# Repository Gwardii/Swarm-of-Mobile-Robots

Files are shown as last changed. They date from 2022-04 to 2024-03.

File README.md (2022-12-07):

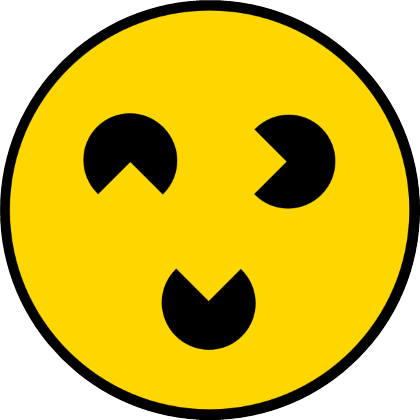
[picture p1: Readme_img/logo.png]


# TGS - The Great Swarm 

Academic project of the swarm of mobile robots - system for controlling and monitoring mobile robots with differential drive. The system consists of a graphical user interface, mobile robot software and software for detecting obstacles. 

## Graphical User Interface
A graphical user interface was created with the use of the Tkinter package. The application allows users to control the mobile robots with the help of control buttons and by assigning the coordinates of the target. In addition, GUI contains a preview of the created map and a preview from the camera mounted above the table where the robots were driving.
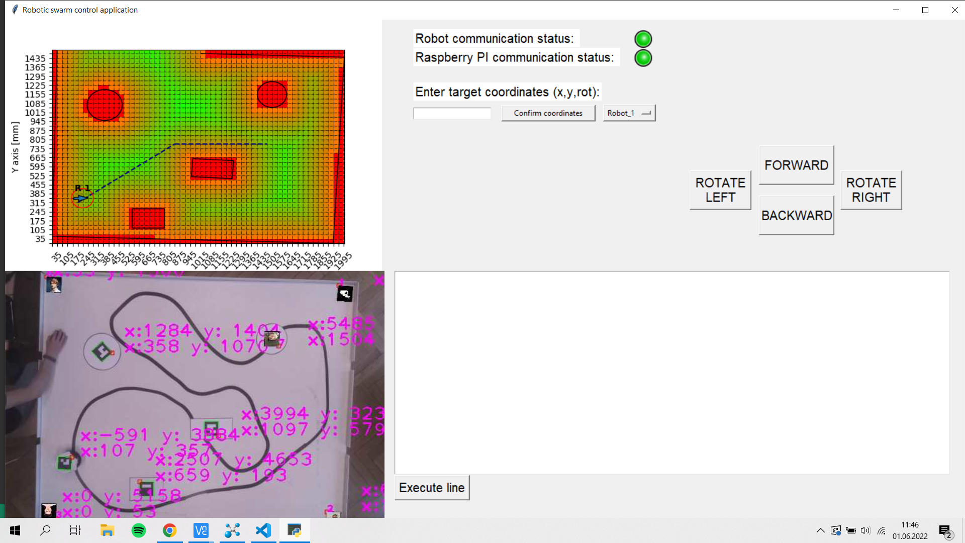
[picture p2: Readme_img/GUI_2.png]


## Raspberry Pi - vision and detection

Raspberry Pi with a mounted camera detects ArUco markers and procces captured images. Four ArUco markers define corners, robots and obstacles are defined as another sets of markers. Coordiantes of all markers are calculated and send to main server. Live stream from Raspberry is load into local webpage (main application take it for visualization).

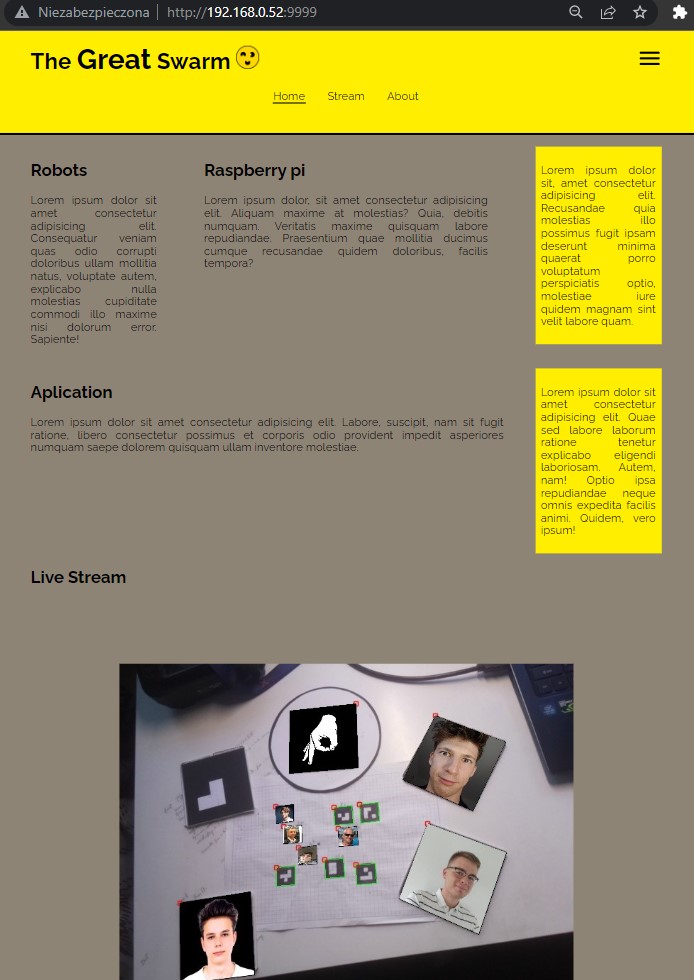
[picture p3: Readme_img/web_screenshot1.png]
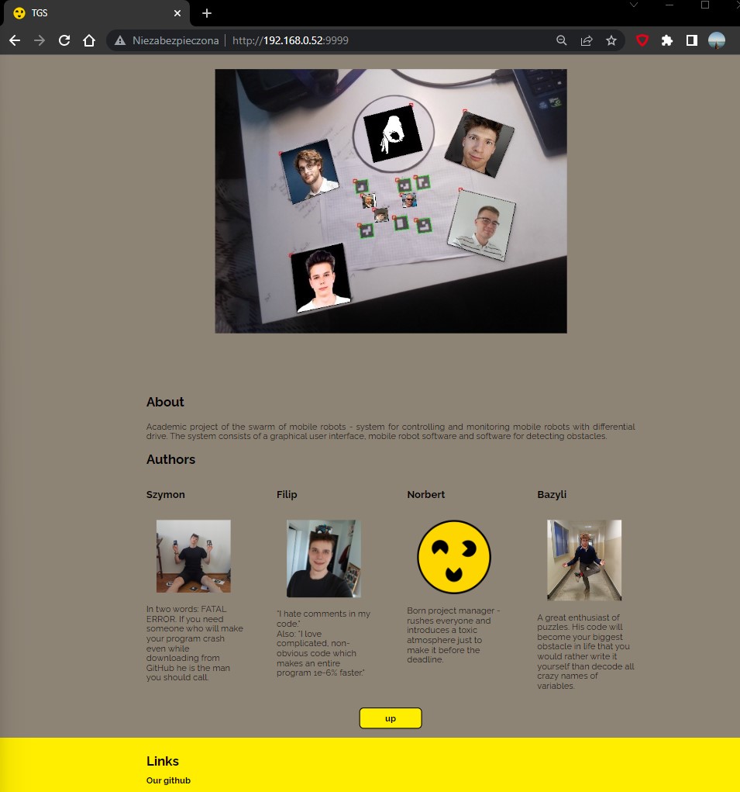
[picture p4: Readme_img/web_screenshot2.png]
 

## Mobile robot software
Robots were built around the Arduino Uno boards. Each of them has two wheels equipped with encoders. The communication with the central computer is realized using the XBeeS1 boards.

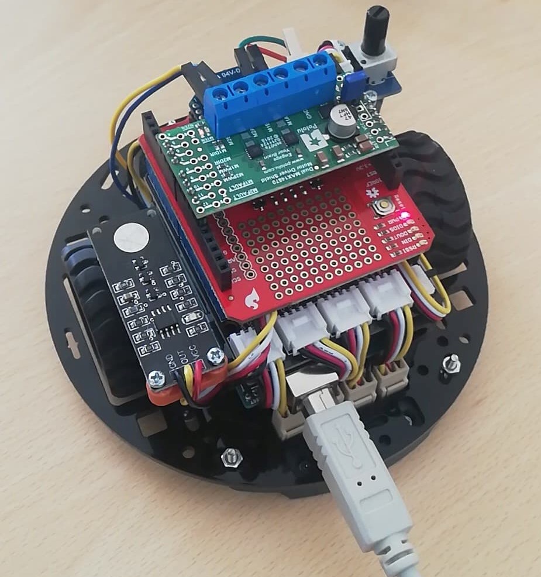
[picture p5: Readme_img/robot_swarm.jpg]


A robot can get the command to wait, move forward, rotate, and move around the given arc. Each command is built so the robot will drive a given distance or angle in a given amount of time.
The main goal while programming robots was to make their path as deterministic as possible. To achieve this, each command consists of the path parametrs such as its length or radius and the time in with the path should be complited. Based on that robot calculates the path for each wheel and follows it using PID.

## Path planning
Implemented path planning algorithm finds the shortest feasible polygonal chain between target and actual position of a robot. The path planner requires a rasterized map of working area, thus it was also covered in the project. At the moment, the rasterization is provided for any polygon and circle, which are should be provided in the specified json format.

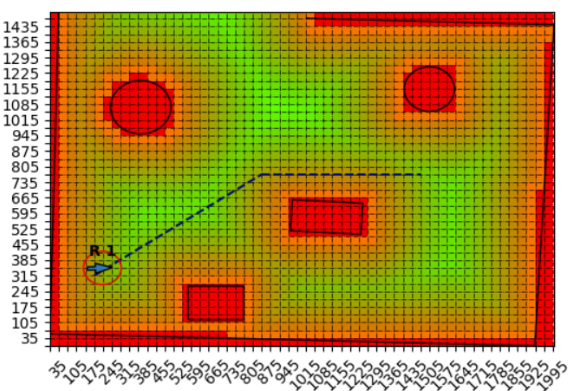
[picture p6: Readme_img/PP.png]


## Authors

- [Szymon Bielenin](https://github.com/symonb)
- [Filip Gwardecki](https://github.com/Gwardii)
- [Bazyli Leczkowski](https://github.com/S4uro0on)
- [Norbert Prokopiuk](https://github.com/norbertprokopiuk)

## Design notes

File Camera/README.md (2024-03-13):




# TGS - Raspberry PI

This page is all about how to configure and set up Raspberry PI, and OpenCV. Also, there are descriptions of functions and programs which run on RPI.

<br/>

## Set up Raspberry Pi

In our case RPI is 3B+ but probably most of the advice will be valid on different models.

- install Rasbian (OS for your RPI) by following the original page: https://www.raspberrypi.com/software/
- enable: SSH, VNC

### How do you get the IP of your RPI?
To use your RPI only with your computer you need to get the IP of your RPI. You can connect the monitor, mouse and keyboard, log in and get IP with the command "ifconfig",
also if you enabled VNC IP will be shown if you click on the VNC icon in the right-up corner. But these methods are not useful if you want to connect to new wifi
or you just don't have a monitor and mouse and keyboard with you.\
<br/>
So instead, you want to connect with your raspberrypi with an ethernet cable and next connect with SSH to your RPI.\
You can use PuTTy:
<br/>
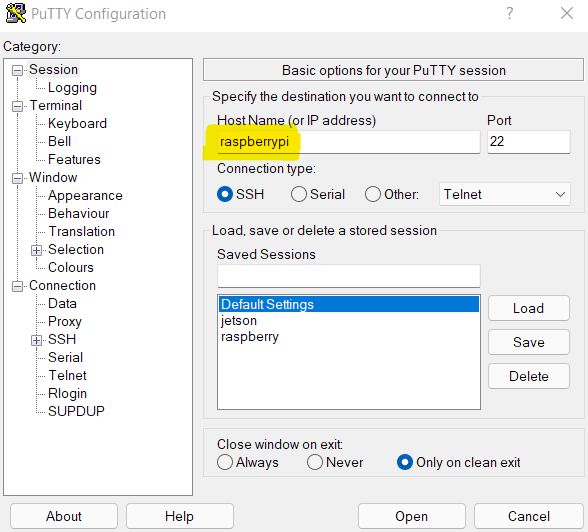
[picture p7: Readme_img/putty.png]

<br/>
or Windows terminal:
```
> ssh pi@raspberrypi
```
<br/>
or VNC Viewer (preferred method - now, you can use a remote desktop!):
<br/>
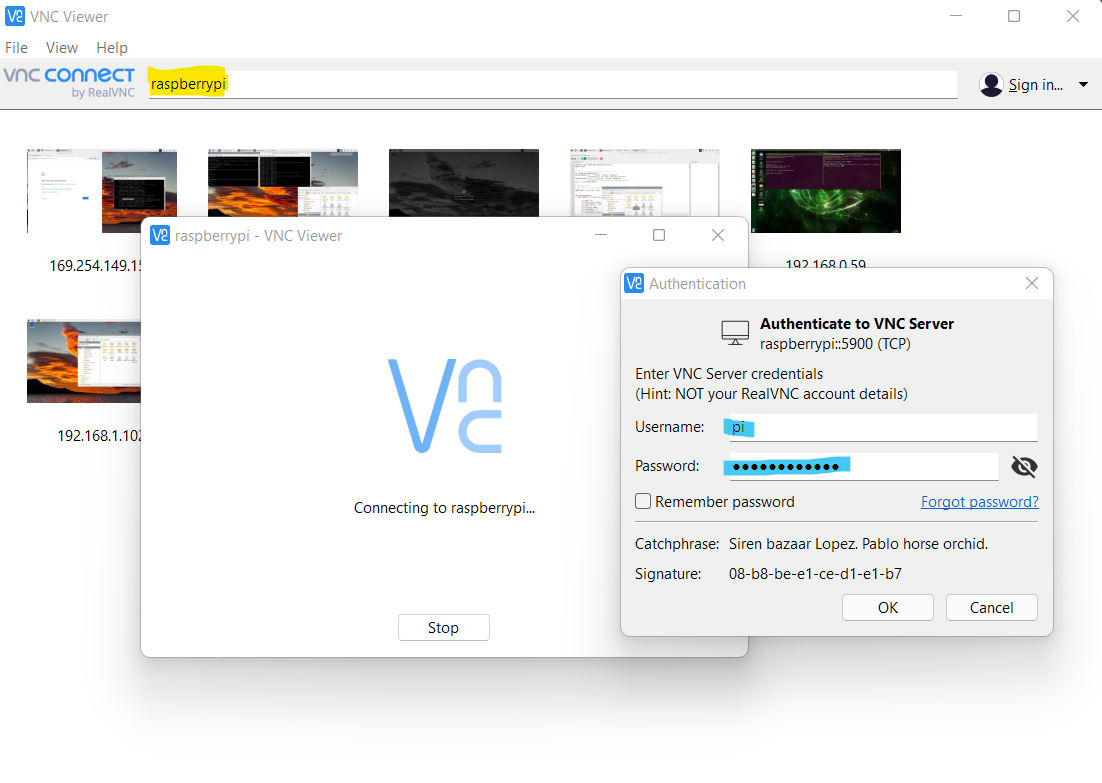
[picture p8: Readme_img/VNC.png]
 

\* if "raspberrypi" doesn't work you can try "raspberrypi.local"

Next, you can check for the IP of your RPI:

```
pi@raspberrypi:~ $ ifconfig
```
Also, at this point, you can connect to wifi and read IP. 

Once you get the IP of your RPI in the network you can disconnect the ethernet cable and use one of the previous methods to connect with your RPI wireless. 

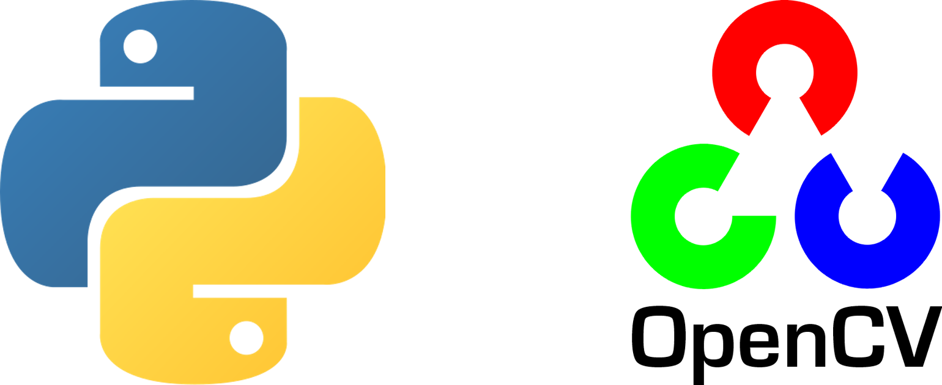
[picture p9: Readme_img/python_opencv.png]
 

## Installing OpenCV

There are a lot of tutorials on how to do this and if you manage to do this with them good for you! 
But if you are not familiar with RPI, python, Linux and OpenCV (as I was) maybe these tips will be helpful and save some of your time.
At beginning, a tutorial which I suggest to follow: [link](https://pyimagesearch.com/2018/09/26/install-opencv-4-on-your-raspberry-pi/).
With some changes, this was the right one. Follow the steps:
- expand filesystem
- uninstall unnecessary programs (optional)
- install Cmake and all libraries and packages (be aware of versions which you install)
- install python3
- download OpenCV 4.X.X - you can download the latest version just change all commands 4.0.0 to your version (we used 4.5.5)
- Configure Python virtual environment (optional) 
- install NumPy
- setup compile with CMake and run cmake to compile OpenCV - check if you don't have any errors! 
- increase swap space: [link](https://pimylifeup.com/raspberry-pi-swap-file/) (use this steps)
- compile OpenCV 4.X.X: make -j4 (if sth crash restart RPI go to this directory and type: make -j1, compilation will be continued) with -j1 it can last even >10 hrs
- after compilation install OpenCV (check if there are no errors!)
- reduce swap space (back to 100 MB): [link](https://pimylifeup.com/raspberry-pi-swap-file/)
- Last step (different as in the tutorial)
  - find and go into ../python3.[X](https://your_python_version)/site-packages
  - find path for ../python-3.[X](https://your_python_version)/cv2.cpython-3[X](https://your_python_version)m-arm-linux-gnueabihf.so (in our case: "/usr/local/lib/python3.9/site-packages/cv2/python-3.9/cv2.cpython-39-arm-linux-gnueabihf.so"
  - create symbolic link ( ```ln -s ../path_to_XXX.so cv2.so ```)
 - test if OpenCV is working:
 ```
 $ python
 >>>import cv2
 >>>cv2.__version__
  ```
  If you receive your OpenCV version you are ready to use it!
  
  ## Aruco detection
  
  The most important functionality of RPI is detecting Aruco markers and saving their coordinates. But     before you want to use any camera with OpenCV you should calibrate  it.
  It is a necessary step to reduce fish-eye effect and to achieve good results in the next steps.  
  Also, it is worth knowing that Aruco markers should have some light frame around a black one or be mounted on a light background (necessary for detection of the black square).  
  ### Calibration
  
  First of all, you need to take a few pictures of the calibration grid. You can use a special script to do this:
  ```
  $ python ./Camera/capture_frame.py
  ```
  You can use any grid you want ([link](https://markhedleyjones.com/projects/calibration-checkerboard-collection)) but you need to set your parameters in ```       camera_calibration.py```:
  ```
  # Define the dimensions of the checkerboard
  # How many corners can be found:
  # horizontal and vertical
  # also size of the side of a square in [mm])
  CHECKERBOARD = (8, 5, 251/9)
  ```
  Next, you can run:```$ python ./Camera/camera_calibration.py``` and
  calibration file will be saved as "./Camera/camera_calibration.npy".
  Example with correctly detected grid:
  <br/>
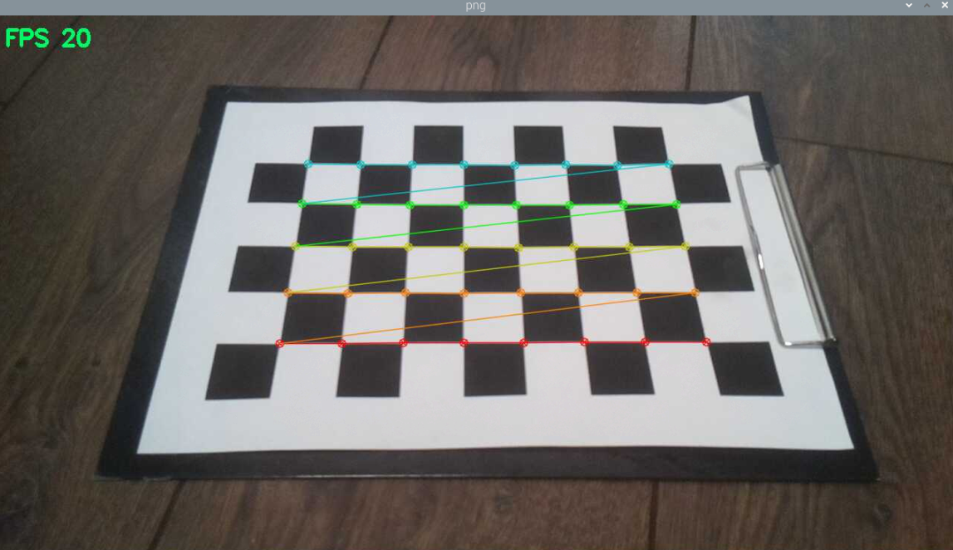
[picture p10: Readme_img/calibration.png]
   

  ### aruco_detection.py
  
  The main program for aruco detection has 2 options:
  -  -d (display) if 0 there will be no display window, preferred if you want to increase FPS (default is 1)
  -  -js (json sending) if 0 json files will not be sent to the server (default is 1)
  
  it is important to run this from the correct directory:
  ```
  $ python ./Camera/aruco_detection.py -d 1 -js 0
  ```
  Also, if you want to connect with the main server (send jsons), it is needed to set the correct IP and port of   the server at the beginning of aruco_detection.py:
  ```
  # --------------USER SETTINGS---------------

  server_IP = "192.168.12.120"
  server_PORT = 9999

  # camera setting:
  resolution = [640, 480]
  FPS = 40
  ```
  
  ### state_machine_RPI.py
  
aruco_detection.py based on "if" statements which was good enough but with the development of this project new functionality will be added. Also remembering all flags is not so easy after some time. So, we decided to create a Finite State Machine (FSM). This concept is really useful to organize all functionality and allows to add in easy way new ones. In a nutshell, FSM is based on states (which all are defined at the beginning) and transitions which allow for changes between states. Each state has arbitrarily defined all possible transitions. FSM usually doesn't provide less code but its purpose is to give more orderly and clear code. For more info about FSM see [link](https://brilliant.org/wiki/finite-state-machines/), [link](https://www.youtube.com/watch?v=2OiWs-h_M3A). 
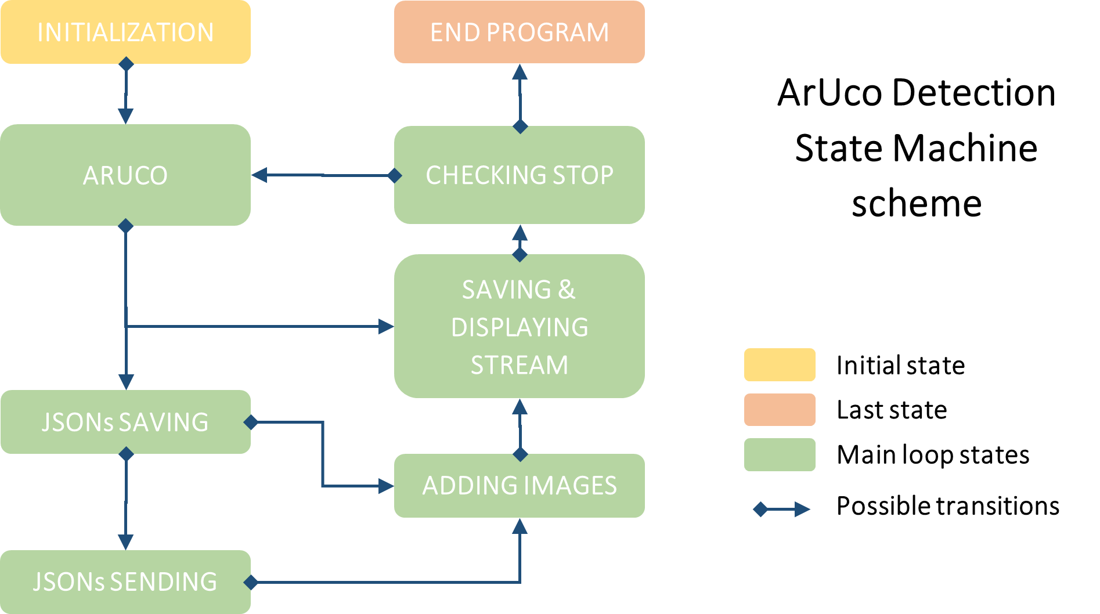
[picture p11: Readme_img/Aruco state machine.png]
 
 <br/>
 
All states and transitions are shown on this diagram. Each of the states consist of the main function and at the end possible transitions. The main while loop runs only one command and on each iteration, you can check on which state you are in. It is probably not the best solution but for sure it is useful to know the FSM concept and own implementation is the best way to learn this. 

In use there is no difference with aruco_detection.py still all options work:
```
 $ python .\Camera\state_machine_RPI.py -d 0 -js 1   
```
  ### stream.py
  
  For visualization and HTML learning, a simple website was created. Pictures are streamed into this website   from where the main application can feed its display.
  To turn on stream type:
  ```
  $ python ./Camera/stream_tests/flask_version/stream.py
  ```

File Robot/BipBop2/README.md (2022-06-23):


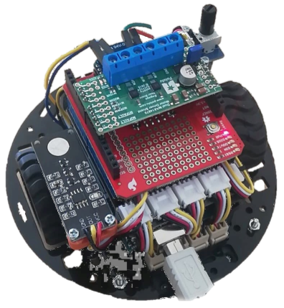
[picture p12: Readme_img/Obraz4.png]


## TGS - Robot

This page is all about how to configure robot and communicate it with the server. The robot is shown on the picture on the right. It is based on the Arduino Uno board, has two wheels and communicate with the server via XBee.

## Commands

In order for the robot to move freely around the table to avoid obstacles, it must be able to follow several commands:
1. Stay in the spot for a given amount of time
2. Travel a certain distance forwards and backwards
3. Rotate left or right at a given angle
4. Travel a given distance in a given arc

## Commands execution

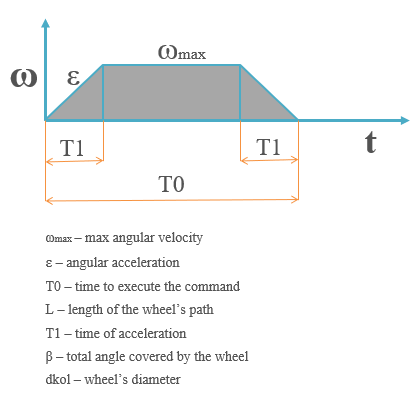
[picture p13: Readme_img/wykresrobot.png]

<br/>

To be able to handle a sworm of robots, the way each one executes a command should be the same. For this to be possible, in addition to movement parameters such as distance or angle, the time for execution of the command is also given. 

When given the command to move, the robot calculates the distance each of its wheels must travel. Then calculates a trapezoidal velocity profile (shown on the figure) with its integral corresponding to the path of the wheel. The angular acceleration of robots is constant and equal 5 * 0.000001 deg/ms2. 

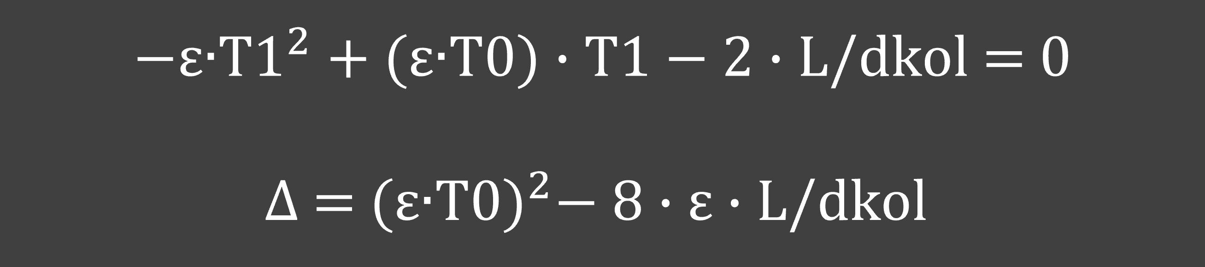
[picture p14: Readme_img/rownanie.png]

<br/>
<br/>
<br/>

By integrating the velocity diagram shown in the graph, we obtain the equation shown above. The only unknown in this equation is T1. It is worth mentioning that the discriminant of this equation (shown below) allows us to check whether it is possible to execute received command with given parameters.

When executing the command every 30 ms the robot calculates what position each of its wheels should be in and turns them to that position using the PID controller.

## XBEE Communication
The XBee board communicates with Arduino using Serial. When the message is received, Serial interrupt is used to stack it an array of robot commands. The frame of the message is shown below and is the same as the one schown in the "computer" part of the project.

Header (0x20 0x40) | Task_ID | Distance (mm) | Task Time (ms)| Radius (mm) | Rotation (deg)| Ender (0x50 0x60)  | Checksum   |
-------------------| --------|---------------|---------------|-------------|---------------|--------------------|------------|
2 bytes            | 1 byte  | 2 bytes       | 3 bytes       | 2 bytes     | 2 bytes       | 2 bytes            | 2 bytes    |

When the robot gets the first message It immediately starts to execute it. When the time allocated to execute the command passes, the robot starts executing the next command.

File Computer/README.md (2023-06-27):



### TGS - MAIN COMPUTER

This page is about the main computer which is a brain of a whole swarm. It computes paths, decides on the movements of the robots, and communicates with them. Also, it runs the main GUI and receives data from RPI. Below are descriptions of functions and programs that run on the main computer.

<br/>

### application.py

Main script which starts all the others. After starting the application initialization starts: the application will try to communicate with RPI and receive JSON from it. After 10 [s] without receiving data, it will be terminated and GUI will start to generate. 
The only setting you need to do is to provide IP, PORT of RPI, number of used robots and XBEE mode at the beginning of the program:
```
# --------------USER SETTINGS---------------

RPI_IP = "192.168.12.120" #set 0 to use your computer camera
RPI_PORT = 9999
NUMBER_OF_ROBOTS = 1
XBEE = True

# -----------END OF USER SETTING-----------
```
#### State machine

In order to provide a more orderly and readable code state machine was implemented. All states and possible transitions are shown on the diagram below:

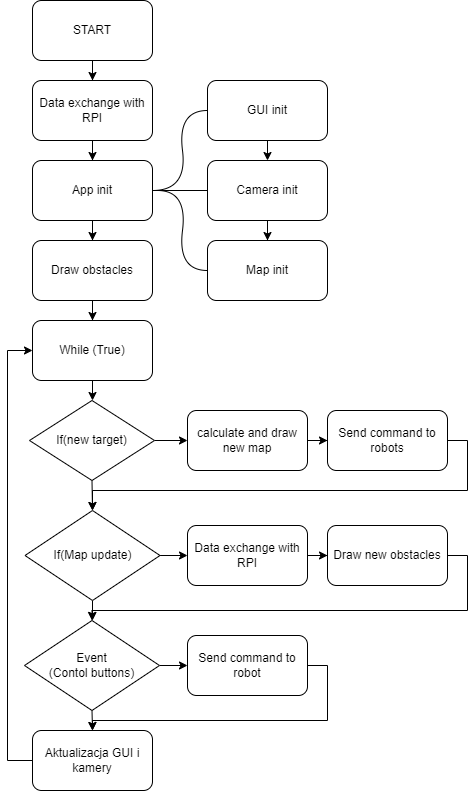
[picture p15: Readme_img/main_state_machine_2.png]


All states are implemented as separate classes inherited from a state base class. In this way, all classes have a similar structure and it's easy to figure out what is the task of each state. In addition, a structure like this allows for the easy and quick adding new states. It is important to mention that a state also can be a separate state machine containing some smaller states. In this project, the state Initialization was implemented as another state machine so if you want to implement something like this refer to the class Initialization in states.py. 
The same concept of state machine was used in the Camera state machine so, in order to don't repeat the same information, only this one has a detailed description of an action. 

### Adding new states
In order to add a new state, you have to create a new class inherited from the class State. In the next step in the Execute function put the code of actions performed by this new state. 
Later add your state to the AllStates and the AllTransitions classes, which contain names of all possible states and transitions. At the end add your state to state and transition initialization. In order to do that go to application.py and in the _states_initialization and _transition_initialization initialize a new class like classes already added.

### GUI

GUI was created to provide some feedback, visualization and also interaction with Swarm. The final version of GUI is presented in the photo below. 



GUI allows controlling each robot by controlling buttons and also by setting target coordinates. In addition, the app provides a live camera view and information about communication status. The simple terminal enables updating the displayed map with the "update" command. It also can be used to display messages to help debug applications. 

### MAP GENERATION

The displayed map is created based on JSON files received from RPI, and information about all possible obstacles is read from the database. The application receives three JSON files: area.json, obstacles.json and robot.json. The area.json contains the coordinates of all working area corners. Obstacles.json contains coordinates (x, y, rotation) and the id of detected obstacles.  Robots.json contains coordinates (x,y, rotation) and the id of detected robots. In the next step, the map is rasterized because path generation is based on a diffusion algorithm. The map is divided into cells with a given dimension (dimension can be set in application settings). Later each cell's weight is calculated and saved to a 2D array. These values are later used for path computation and visualisation of cells state (gradient informing about the distance to obstacles) 

### PATH COMPUTING
The path planning algorithm is divided into 3 steps:
#### Pre-processing
Once a raster map is obtained, its cells are characterised by their distance from the nearest obstacle or workspace boundary. Next, for each of the robots in this map, available cells are determined based on the radius of the robot. If the robot does not have a circular shape it should be written in a circle and then represented by it. The first step should be processed at the beginning or whenever the map changes.
#### Solver
It is an implementation of a diffusion algorithm for pathfinding. Before moving on, naively check if a path can be traced as a single line between a target and an actual location. If so, return the line as the path and do not include the robot in the diffusion path search. For each robot, an artificial potential field is created. The field has the highest value in the target cell and its values propagate from the cell onto another cell like a wave - assign neighbouring cells lower values and repeat for not assigned cells yet. Next, the path is determined as a chain of cells where the first cell is an actual position of a robot and each successive cell is a neighbour with the highest value.
#### Post-processing
The obtained paths are lists of particular cells, however, the most optimal way to store and transmit paths is to describe them as a polygonal chain. For this purpose, a simple recursive minimalization of a route is implemented.

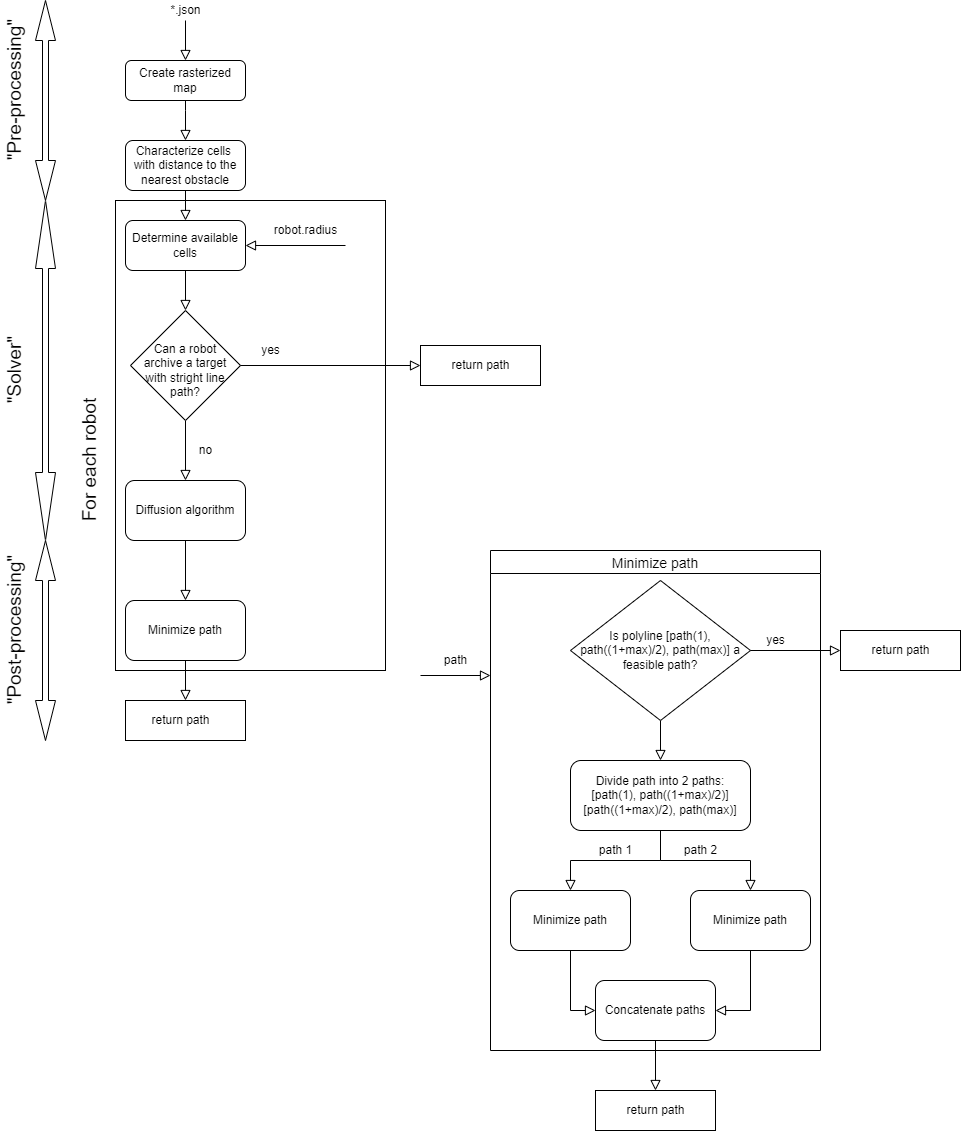
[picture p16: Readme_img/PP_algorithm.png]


### ROBOT COMMUNICATION 
#### XBEE INITIALIZATION
Communication with robots was created with the XBEE module. Before usage, each module has to be initialized. You can do it using XCTU application provided by the producer. To do it you have to plug XBEE module into your computer, launch XCTU and find connected devices by clicking on the "Discover devices" icon in the upper left corner. Next set all data in the displayed window. When your XBEE is discovered you have to change some settings viewed in the table on the right side. Values to change:

- Channel = C
- PAN ID = CAFE
- AP API Enable = API enabled [1]
         
All used XBEE have to be initialized. It has to be done only at your first usage. When all modules are initialized connect XBEE to a robot and in XCTU app click the icon "Find devices in network". When modules were found PC can exchange data with each module. 

#### XBEE Data Frame
To communicate with XBEE digi.xbee Python library was used. This library contains functions to communicate with XBEE in an "easy" way. To communicate with XBEE string or byte array can be used. In this project decided to use a byte array. Each message was prepared on the basis of the frame in the table below:

Header (0x20 0x40) | Task_ID | Distance (mm) | Task Time (ms)| Radius (mm) | Rotation (deg)| Ender (0x50 0x60)  | Checksum   |
-------------------| --------|---------------|---------------|-------------|---------------|--------------------|------------|
2 bytes            | 1 byte  | 2 bytes       | 3 bytes       | 2 bytes     | 2 bytes       | 2 bytes            | 2 bytes    |

It's important to mention that by default, XBee adds 8 bytes of preamble with the destination device address. It can be helpful if you want to use a broadcast mode of communication but in this project, unicast mode was used so information about an address was ignored. Without this knowledge communication with XBEE can be tricky.

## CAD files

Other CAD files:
Computer/modele/OldVersions/stol_1.0001.ipt
Computer/modele/OldVersions/stoł_2.0004.iam
Computer/modele/Part3.ipt
Computer/modele/stol_1.ipt
Computer/modele/stoł_2.iam
Computer/modele/stoł_2/Frame/Frame 1647020232368.iam
Computer/modele/stoł_2/Frame/ISO 10799-2 40x40x2 1647020233901.ipt
Computer/modele/stoł_2/Frame/ISO 10799-2 40x40x2 1647020233947.ipt
Computer/modele/stoł_2/Frame/ISO 10799-2 40x40x2 1647020233997.ipt
Computer/modele/stoł_2/Frame/ISO 10799-2 40x40x2 1647020234043.ipt
Computer/modele/stoł_2/Frame/ISO 10799-2 40x40x2 1647020234088.ipt
Computer/modele/stoł_2/Frame/ISO 10799-2 40x40x2 1647020234135.ipt
Computer/modele/stoł_2/Frame/ISO 10799-2 40x40x2 1647020234181.ipt
Computer/modele/stoł_2/Frame/ISO 10799-2 40x40x2 1647020234225.ipt
Computer/modele/stoł_2/Frame/ISO 10799-2 40x40x2 1647020234270.ipt
Computer/modele/stoł_2/Frame/ISO 10799-2 40x40x2 1647020234319.ipt
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

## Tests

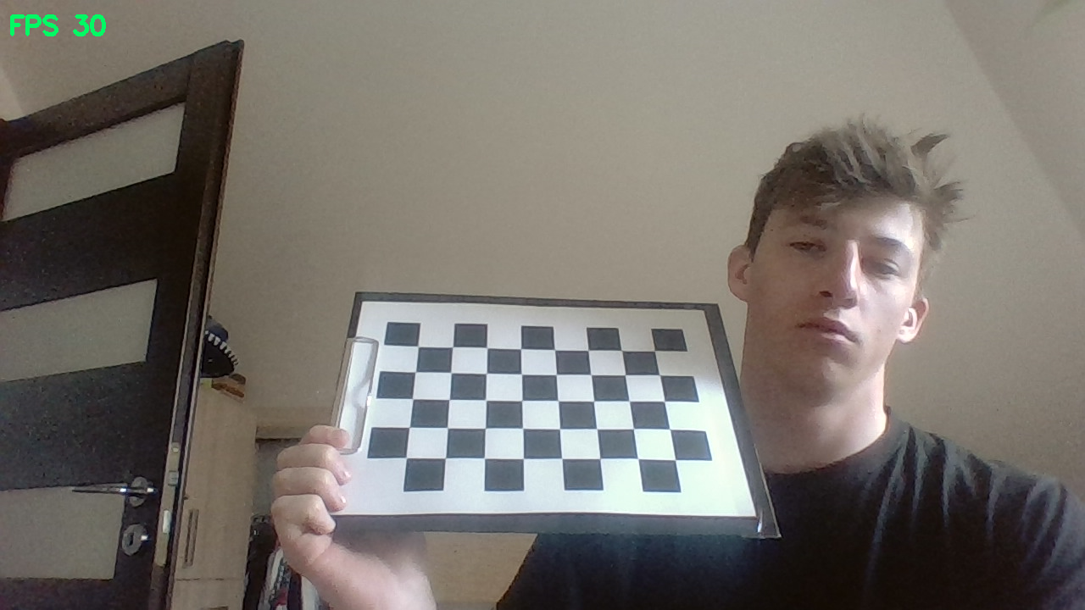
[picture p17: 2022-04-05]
Camera/captured_frames/calibration_img_6.png

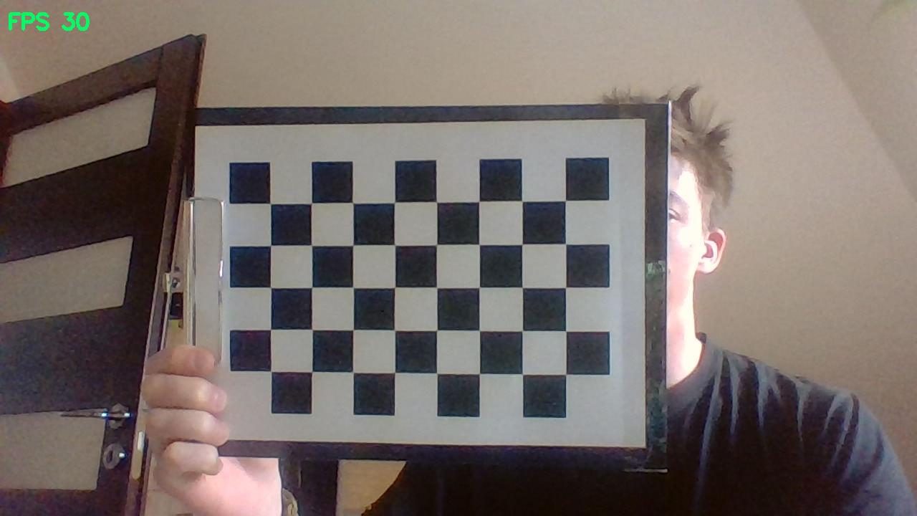
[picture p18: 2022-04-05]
Camera/captured_frames/calibration_img_0.png

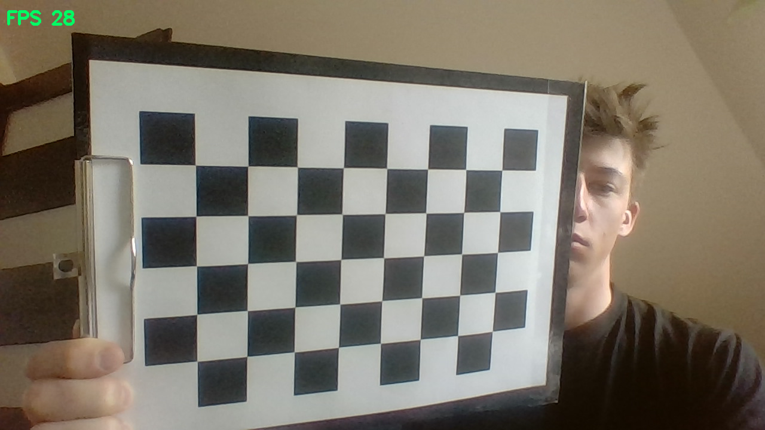
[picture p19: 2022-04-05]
Camera/captured_frames/calibration_img_5.png

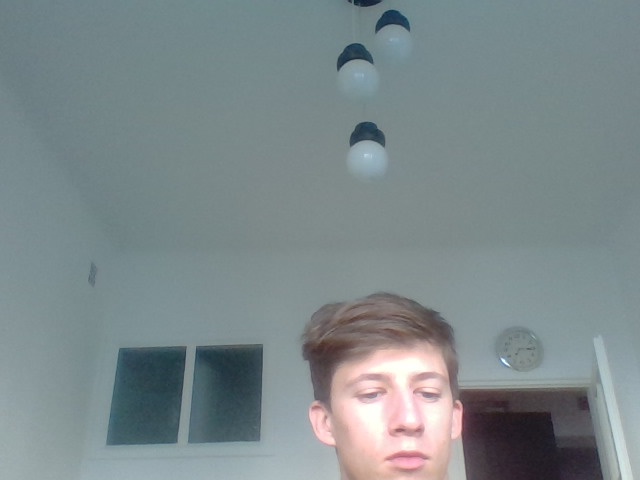
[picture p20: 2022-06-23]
Camera/stream_tests/flask_version/stream/stream.jpg

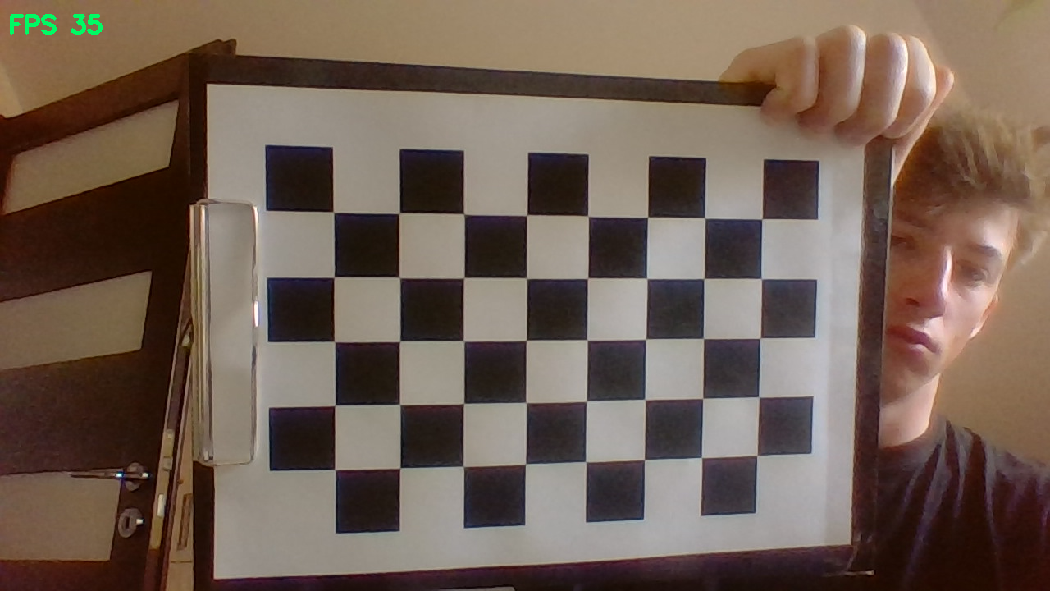
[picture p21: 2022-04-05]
Camera/captured_frames/calibration_img_10.png

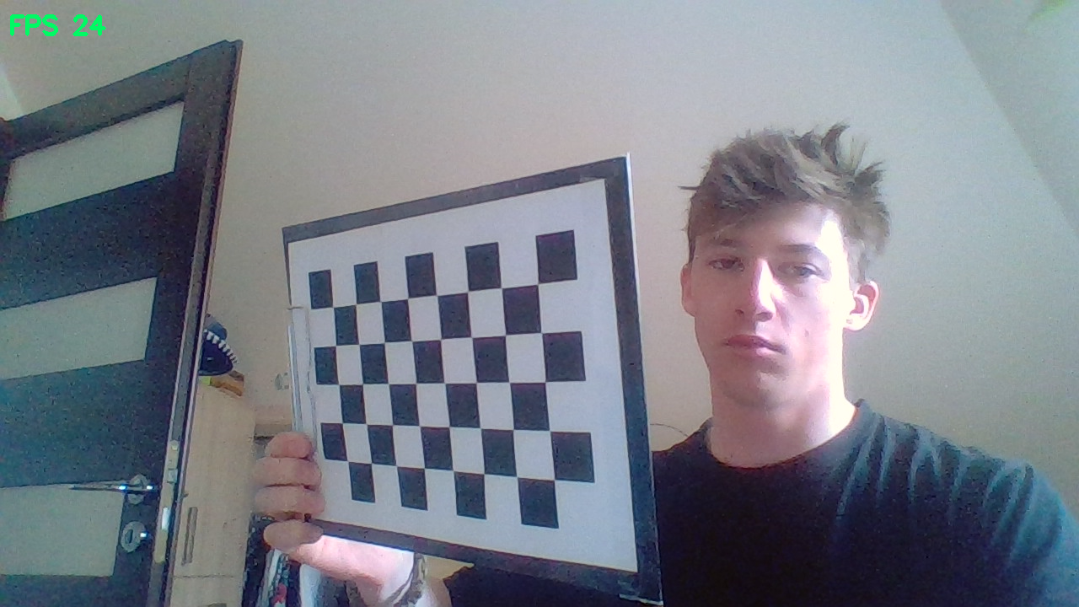
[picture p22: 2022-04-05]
Camera/captured_frames/calibration_img_4.png

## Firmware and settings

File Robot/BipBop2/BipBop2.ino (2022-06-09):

///PID///
const float kd = 2;
const float kp = 6;
const float ki = 0;

double dt;
double last_t = 0;


///Xbee///
static bool started = false; //True: Message is started
static bool ended   = false;//True: Message is finished
char incomingByte ; //Variable to store the incoming byte
char msg[3];    //Message - array from 0 to 2 (3 values - PWM - e.g. 240)
byte index;     //Index of array
int value = 0;
double Tjazda;
uint8_t XbeeGetTab[25];
static int XIndex = 0;


///Parametry Ruchu///
double epsilon = 5 * 0.000001; //przyspieszenie katowe [deg/ms2]
double t_Start;
double t_End;


///Konfiguracja napedow///
const byte silnik_1_A = 2;
const byte silnik_1_B = 5;
const byte silnik_2_A = 3;
const byte silnik_2_B = 6;

const int pin_kierunek_silnik_lewy = 7;
const int pin_PWM_silnik_lewy = 9;
const int pin_kierunek_silnik_prawy = 8 ;
const int pin_PWM_silnik_prawy = 10;

int wartosc_PWM_1_silnik_lewy = 0;
int wartosc_PWM_1_silnik_prawy = 0;
int PWM_max = 255;

long long silnik_1; //Lewy silnik
long long silnik_2; //Prawy silnik

double kat_1; //Odczyt lewego enkodera
double kat_2; //Odczyt prawego enkodera

//Zmienne odczytu enkodera
int state_1_A;
int state_1_B;
int state_2_A;
int state_2_B;

///Konfiguracja potencjometru///
long potencjometr = 0;
const byte pin_potencjometr = 5;

///Lewy silnik PWM konfiguracja///
double suma_bledow_1 = 0;
long long kat_obrot_1 = 0;
float wartosc_PWM_1;
float uchyb_silnik_1 = 0;
float last_uchyb_silnik_1 = 0;
float szybk_bledow_1;

///Prawy silnik PWM konfiguracja///
double suma_bledow_2 = 0;
long long kat_obrot_2 = 0;
float wartosc_PWM_2;
float uchyb_silnik_2 = 0;
float last_uchyb_silnik_2 = 0;
float szybk_bledow_2;

///Parametry robota///
const float d_kola = 42;
const float rozstaw = 94;

///Zmienne odometria///
int dp1, dp2;
int dp1_last, dp2_last;
double Dl, Dp;
double D, D_last;
float rot = 0, rot_d = 0;
double x_n, y_n;

///Odbior///
const int tabN = 20;
struct Task {
  uint8_t id;
  uint16_t distance;
  uint32_t _time;
  uint16_t radius;
  uint16_t orientation;

};
struct Task tablica[tabN]; //tablica do odbioru danych o zadaniu. {Nr zadania, dlugosc (prosta/luk) [mm], czas wykonania [ms], promien luku [mm], kat rotacji w miejscu [deg]}
uint8_t tablica_empty_id = 0;
float bufor[5] = {0, 0, 0, 0, 0};
float T1, beta, delta, L_obr;
uint16_t *L, *Mi;
uint32_t *T0;

///Pozostałe zmienne///
double petla_t1 = 0;
float Xt = 10;
double zad_t = 0; //Czas rozpoczecia wykonywania zadania
double T1_now;
double T0_now;
double katL0;
double katP0;
double L1, L2;
int a;

void setup() {
  pinMode(silnik_1_A, INPUT_PULLUP);
  pinMode(silnik_2_A, INPUT_PULLUP);
  attachInterrupt(digitalPinToInterrupt(silnik_1_A), odczyt_1, CHANGE);
  attachInterrupt(digitalPinToInterrupt(silnik_2_A), odczyt_2, CHANGE);

  pinMode(pin_kierunek_silnik_lewy, OUTPUT);
  pinMode(pin_PWM_silnik_lewy, OUTPUT);
  pinMode(pin_kierunek_silnik_prawy, OUTPUT);
  pinMode(pin_PWM_silnik_prawy, OUTPUT);

  Serial.begin(9600);

  T0 = &tablica[0]._time;
  L = &tablica[0].distance;
  Mi = &tablica[0].orientation;
}

void loop() {
  //Petla co Xt ms, obsługa zadania
  if ((millis() - petla_t1) >= Xt) {
    petla_t1 = millis();
    if (tablica_empty_id > 0) { //Czy jest komenda do wykonania?

      if (tablica[0].id == 1)//Stoj przez ...
        if (zad_t == 0)
          zad_t = millis(); //Jeżeli zadanie już nie trwa, zapisz czas rozpoczecia


      if (tablica[0].id == 2) {//Jedz prosto przod
        //delta=Eps^2*T0^2-4*Eps*2*L/dk
        while (((epsilon * epsilon) * (*T0 * *T0) - 8 * epsilon / d_kola * *L) < 0);
        if (zad_t == 0) {//Czy to rozpoczecie komendy?
          zad_t = millis(); //Jeżeli zadanie jeszcze nie trwa, zapisz czas rozpoczecia
          //Parametry ruchu
          delta = (epsilon * epsilon) * (*T0 * *T0) - 8 * epsilon / d_kola * *L;
          if (delta < 0) Serial.println("Zle zadany ruch");
          T1 = *T0 / 2. - sqrt(delta) / 2 / epsilon;
          T1_now = zad_t + T1;
          T0_now = zad_t + *T0;
          katL0 = kat_1;
          katP0 = kat_2;
        }
        prosto();
      }

      if (tablica[0].id == 3) {//Jedz prosto tyl
        while (((epsilon * epsilon) * (*T0 * *T0) - 8 * epsilon / d_kola * *L) < 0);
        if (zad_t == 0) {//Czy to rozpoczecie komendy?
          zad_t = millis(); //Jeżeli zadanie jeszcze nie trwa, zapisz czas rozpoczecia
          //Parametry ruchu
          delta = (epsilon * epsilon) * (*T0 * *T0) - 8 * epsilon / d_kola * *L;
          if (delta < 0) while(1);
          T1 = *T0 / 2. - sqrt(delta) / 2 / epsilon;
          T1_now = zad_t + T1;
          T0_now = zad_t + *T0;
          katL0 = kat_1;
          katP0 = kat_2;
        }
        tyl();
      }

      if (tablica[0].id == 4) {//Obrot
        while (((epsilon * epsilon) * (*T0 * *T0) - 8 * epsilon / d_kola * (*Mi / 180 * 3.1416 * rozstaw / 2)) < 0);
        if (zad_t == 0) {//Czy to rozpoczecie komendy?
          zad_t = millis(); //Jeżeli zadanie jeszcze nie trwa, zapisz czas rozpoczecia
          //Parametry ruchu
          if (*Mi > 0) a = 1; else a = -1;
          L_obr = a**Mi / 180. * 3.1416 * rozstaw / 2;
          delta = (epsilon * epsilon) * (*T0 * *T0) - 8 * epsilon / d_kola * L_obr;
          if (delta < 0) while(1);
          T1 = *T0 / 2. - sqrt(delta) / 2 / epsilon;
          T1_now = zad_t + T1;
          T0_now = zad_t + *T0;
          katL0 = kat_1;
          katP0 = kat_2;
        }
        obrotL();
      }

      if (tablica[0].id == 5) {//Obrot
        //L=(Mi/180*3.1416 * roz/ 2) %obrot
        while (((epsilon * epsilon) * (*T0 * *T0) - 8 * epsilon / d_kola * (*Mi / 180 * 3.1416 * rozstaw / 2)) < 0);
        if (zad_t == 0) {//Czy to rozpoczecie komendy?
          zad_t = millis(); //Jeżeli zadanie jeszcze nie trwa, zapisz czas rozpoczecia
          //Parametry ruchu
          if (*Mi > 0) a = 1; else a = -1;
          L_obr = a**Mi / 180. * 3.1416 * rozstaw / 2;
          delta = (epsilon * epsilon) * (*T0 * *T0) - 8 * epsilon / d_kola * L_obr;
          if (delta < 0) while(1);
          T1 = *T0 / 2. - sqrt(delta) / 2 / epsilon;
          T1_now = zad_t + T1;
          T0_now = zad_t + *T0;
          katL0 = kat_1;
          katP0 = kat_2;
        }
        obrotP();
      }


      if (tablica[0].id == 6 || tablica[0].id == 7) {//Luk
        //%L=(*L/tablica[0].radius*(tablica[0].radius+rozstaw/2)) %luk
        while (((epsilon * epsilon) * (*T0 * *T0) - 8 * epsilon / d_kola * (*L / tablica[0].radius * (tablica[0].radius + rozstaw / 2))) < 0);
        if (zad_t == 0) {//Czy to rozpoczecie komendy?
          zad_t = millis(); //Jeżeli zadanie jeszcze nie trwa, zapisz czas rozpoczecia
          //Parametry ruchu
          delta = (epsilon * epsilon) * (*T0 * *T0) - 8 * epsilon / d_kola * *L;
          if (delta < 0) while(1);
          T1 = *T0 / 2. - sqrt(delta) / 2 / epsilon;
          T1_now = zad_t + T1;
          T0_now = zad_t + *T0;
          katL0 = kat_1;
          katP0 = kat_2;
        }
        luk();
      }

      if (millis() - zad_t > tablica[0]._time) koniec_CMD(); //Uplynal czas na wykonanie komendy
    }
  }

  PWM(); //PWM na napedy

  odometria();
  delay(1);
}

///Obsługa wiadomości od XBee///
void serialEvent() {F
  uint16_t ChSum = 0; //Check Sum
  while (Serial.available() < 25);
  Serial.readBytes((char*)XbeeGetTab, 8);
  Serial.readBytes((char*)XbeeGetTab, 16);
  Serial.read();
  if ((XbeeGetTab[0] != 0x20) || (XbeeGetTab[1] != 0x40) || (XbeeGetTab[14] != 0x50) || (XbeeGetTab[15] != 0x60))
    return;
  for (int elo = 0; elo < 12; elo++) {
    ChSum += XbeeGetTab[elo];
  }
  if (((((uint16_t)XbeeGetTab[12]) << 8) | XbeeGetTab[13]) == ChSum)
  {
    tablica[tablica_empty_id].id = XbeeGetTab[2];
    tablica[tablica_empty_id].distance = (((uint16_t)XbeeGetTab[3]) << 8) | XbeeGetTab[4];
    tablica[tablica_empty_id]._time = ((((uint32_t)XbeeGetTab[5]) << 16) | (((uint32_t)XbeeGetTab[6]) << 8)) | XbeeGetTab[7];
    tablica[tablica_empty_id].radius = (((uint16_t)XbeeGetTab[8]) << 8) | XbeeGetTab[9];
    tablica[tablica_empty_id].orientation = (((uint16_t)XbeeGetTab[10]) << 8) | XbeeGetTab[11];
    tablica_empty_id += 1;
  }
}

/*
void HardCodedPelnaPizda() {
  delta = (epsilon * epsilon) * (*T0 * *T0) - 8 * epsilon / d_kola * *L;
  if (delta < 0) Serial.println("Zle zadany ruch");
  T1 = *T0 / 2. - sqrt(delta) / 2 / epsilon;
  T1_now = zad_t + T1;
  T0_now = zad_t + *T0;
  katL0 = kat_1;
  katP0 = kat_2;
  tablica[0].id = 2; //prosto
  tablica[0].distance = 500; //500mm
  tablica[0]._time = 10 * 1000; //w 10 sekund
  tablica_empty_id = 1;
  prosto();
}
*/

void luk() {

  double pr_t = millis();

  //Serial.print("Faza: ");

  double kat_obrot = 0;
  if (pr_t <= T1_now) //Czy przyspiesza?
  {
    //    Serial.print(millis() - zad_t);
    //    Serial.print("ms - petla)");
    //Serial.print(1);
    kat_obrot = epsilon * (pr_t - zad_t) * (pr_t - zad_t) / 2;
  }
  else if (pr_t <= (T0_now - T1))  //Czy stala predkosc?
  {
    //    Serial.print(millis() - zad_t);
    //    Serial.print("ms - petla)");
    //Serial.print(2);
    kat_obrot = epsilon * T1 * T1 / 2 + epsilon * T1 * (pr_t - zad_t - T1);
  }

  else if (pr_t <= T0_now)//Czy zwalnia?
  {
    //    Serial.print(millis() - zad_t);
    //    Serial.print("ms - petla)");
    //Serial.print(3);
    kat_obrot = epsilon * T1 * T1 / 2 + epsilon * T1 * (*T0 - 2 * T1) + epsilon * T1 * (pr_t - zad_t - *T0 + T1) - epsilon * (pr_t - zad_t - *T0 + T1) * (pr_t - zad_t - *T0 + T1) / 2;
  }

  else kat_obrot = epsilon * T1 * T1 / 2 + epsilon * T1 * (*T0 - 2 * T1) + epsilon * T1 * T1 - epsilon * T1 * T1 / 2;

  kat_obrot = kat_obrot / 3.1416 * 180;
  //Serial.print("   Kat:");
  //Serial.println(kat_obrot);
  float aa = rozstaw / 2. / tablica[0].radius;

  if (tablica[0].id == 6) {
    kat_obrot_1 = kat_obrot * (1 - aa) + katL0;
    Serial.println(kat_obrot);
    kat_obrot_2 = kat_obrot * (1 + aa) + katP0;
  }

  if (tablica[0].id == 7) {
    kat_obrot_1 = kat_obrot * (1 + aa) + katL0;
    kat_obrot_2 = kat_obrot * (1 - aa) + katP0;
  }
}

void obrotL() {
  double pr_t = millis();

  //Serial.print("Faza: ");

  double kat_obrot = 0;
  if (pr_t <= T1_now) //Czy przyspiesza?
  {
    //    Serial.print(millis() - zad_t);
    //    Serial.print("ms - petla)");
    //Serial.print(1);
    kat_obrot = epsilon * (pr_t - zad_t) * (pr_t - zad_t) / 2;
  }
  else if (pr_t <= (T0_now - T1))  //Czy stala predkosc?
  {
    //    Serial.print(millis() - zad_t);
    //    Serial.print("ms - petla)");
    //Serial.print(2);
    kat_obrot = epsilon * T1 * T1 / 2 + epsilon * T1 * (pr_t - zad_t - T1);
  }

  else if (pr_t <= T0_now)//Czy zwalnia?
  {
    //    Serial.print(millis() - zad_t);
    //    Serial.print("ms - petla)");
    //Serial.print(3);
    kat_obrot = epsilon * T1 * T1 / 2 + epsilon * T1 * (*T0 - 2 * T1) + epsilon * T1 * (pr_t - zad_t - *T0 + T1) - epsilon * (pr_t - zad_t - *T0 + T1) * (pr_t - zad_t - *T0 + T1) / 2;
  }

  else kat_obrot = epsilon * T1 * T1 / 2 + epsilon * T1 * (*T0 - 2 * T1) + epsilon * T1 * T1 - epsilon * T1 * T1 / 2;

  kat_obrot = kat_obrot / 3.1416 * 180;
  //Serial.print("   Kat:");
  //Serial.println(kat_obrot);
  kat_obrot_1 = -a * kat_obrot + katL0;
  kat_obrot_2 = a * kat_obrot + katP0;
}

void obrotP() {
  double pr_t = millis();

  //Serial.print("Faza: ");

  double kat_obrot = 0;
  if (pr_t <= T1_now) //Czy przyspiesza?
  {
    //    Serial.print(millis() - zad_t);
    //    Serial.print("ms - petla)");
    //Serial.print(1);
    kat_obrot = epsilon * (pr_t - zad_t) * (pr_t - zad_t) / 2;
  }
  else if (pr_t <= (T0_now - T1))  //Czy stala predkosc?
  {
    //    Serial.print(millis() - zad_t);
    //    Serial.print("ms - petla)");
    //Serial.print(2);
    kat_obrot = epsilon * T1 * T1 / 2 + epsilon * T1 * (pr_t - zad_t - T1);
  }

  else if (pr_t <= T0_now)//Czy zwalnia?
  {
    //    Serial.print(millis() - zad_t);
    //    Serial.print("ms - petla)");
    //Serial.print(3);
    kat_obrot = epsilon * T1 * T1 / 2 + epsilon * T1 * (*T0 - 2 * T1) + epsilon * T1 * (pr_t - zad_t - *T0 + T1) - epsilon * (pr_t - zad_t - *T0 + T1) * (pr_t - zad_t - *T0 + T1) / 2;
  }

  else kat_obrot = epsilon * T1 * T1 / 2 + epsilon * T1 * (*T0 - 2 * T1) + epsilon * T1 * T1 - epsilon * T1 * T1 / 2;

  kat_obrot = kat_obrot / 3.1416 * 180;
  //Serial.print("   Kat:");
  //Serial.println(kat_obrot);
  kat_obrot_1 = a * kat_obrot + katL0;
  kat_obrot_2 = -a * kat_obrot + katP0;
}

void prosto() {

  double pr_t = millis();

  //Serial.print("Faza: ");

  double kat_obrot = 0;
  if (pr_t <= T1_now) //Czy przyspiesza?
  {
    //    Serial.print(millis() - zad_t);
    //    Serial.print("ms - petla)");
    //Serial.print(1);
    kat_obrot = epsilon * (pr_t - zad_t) * (pr_t - zad_t) / 2;
  }
  else if (pr_t <= (T0_now - T1))  //Czy stala predkosc?
  {
    //    Serial.print(millis() - zad_t);
    //    Serial.print("ms - petla)");
    //Serial.print(2);
    kat_obrot = epsilon * T1 * T1 / 2 + epsilon * T1 * (pr_t - zad_t - T1);
  }

  else if (pr_t <= T0_now)//Czy zwalnia?
  {
    //    Serial.print(millis() - zad_t);
    //    Serial.print("ms - petla)");
    //Serial.print(3);
    kat_obrot = epsilon * T1 * T1 / 2 + epsilon * T1 * (*T0 - 2 * T1) + epsilon * T1 * (pr_t - zad_t - *T0 + T1) - epsilon * (pr_t - zad_t - *T0 + T1) * (pr_t - zad_t - *T0 + T1) / 2;
  }

  else kat_obrot = epsilon * T1 * T1 / 2 + epsilon * T1 * (*T0 - 2 * T1) + epsilon * T1 * T1 - epsilon * T1 * T1 / 2;

  kat_obrot = kat_obrot / 3.1416 * 180;
  //Serial.print("   Kat:");
  //Serial.println(kat_obrot);
  kat_obrot_1 = kat_obrot + katL0;
  kat_obrot_2 = kat_obrot + katP0;
}

void tyl() {

  double pr_t = millis();

  //Serial.print("Faza: ");

  double kat_obrot = 0;
  if (pr_t <= T1_now) //Czy przyspiesza?
  {
    //    Serial.print(millis() - zad_t);
    //    Serial.print("ms - petla)");
    //Serial.print(1);
    kat_obrot = epsilon * (pr_t - zad_t) * (pr_t - zad_t) / 2;
  }
  else if (pr_t <= (T0_now - T1))  //Czy stala predkosc?
  {
    //    Serial.print(millis() - zad_t);
    //    Serial.print("ms - petla)");
    //Serial.print(2);
    kat_obrot = epsilon * T1 * T1 / 2 + epsilon * T1 * (pr_t - zad_t - T1);
  }

  else if (pr_t <= T0_now)//Czy zwalnia?
  {
    //    Serial.print(millis() - zad_t);
    //    Serial.print("ms - petla)");
    //Serial.print(3);
    kat_obrot = epsilon * T1 * T1 / 2 + epsilon * T1 * (*T0 - 2 * T1) + epsilon * T1 * (pr_t - zad_t - *T0 + T1) - epsilon * (pr_t - zad_t - *T0 + T1) * (pr_t - zad_t - *T0 + T1) / 2;
  }

  else kat_obrot = epsilon * T1 * T1 / 2 + epsilon * T1 * (*T0 - 2 * T1) + epsilon * T1 * T1 - epsilon * T1 * T1 / 2;

  kat_obrot = kat_obrot / 3.1416 * 180;
  //Serial.print("   Kat:");
  //Serial.println(kat_obrot);
  kat_obrot_1 = -kat_obrot + katL0;
  kat_obrot_2 = -kat_obrot + katP0;
}

void koniec_CMD() {
  for (int i = 0; i < tablica_empty_id - 1; i++)
    tablica[i] = tablica[i + 1];
  zad_t = 0;
  tablica_empty_id -= 1;
  tablica[tablica_empty_id].id = 0;
  tablica[tablica_empty_id].distance = 0;
  tablica[tablica_empty_id]._time = 0;
  tablica[tablica_empty_id].radius = 0;
  tablica[tablica_empty_id].orientation = 0;
}

void PWM() {
  dt = millis() - last_t; //
  //Lewy PWM
  uchyb_silnik_1 = kat_obrot_1 - kat_1;
  suma_bledow_1 = suma_bledow_1 + uchyb_silnik_1 * dt; //
  szybk_bledow_1 = (uchyb_silnik_1 - last_uchyb_silnik_1) / dt; //
  wartosc_PWM_1 = abs(uchyb_silnik_1 * kp + ki * suma_bledow_1 + kd * szybk_bledow_1); //

  //Prawy PWM
  uchyb_silnik_2 = kat_obrot_2 - kat_2;
  suma_bledow_2 = suma_bledow_2 + uchyb_silnik_2 * dt; //
  szybk_bledow_2 = (uchyb_silnik_2 - last_uchyb_silnik_2) / dt; //
  wartosc_PWM_2 = abs(uchyb_silnik_2 * kp + ki * suma_bledow_2 + kd * szybk_bledow_2); //

  //Lewy obrot
  if (wartosc_PWM_1 > PWM_max) wartosc_PWM_1 = PWM_max;
  if (uchyb_silnik_1 >= 0)
  {
    digitalWrite(pin_kierunek_silnik_lewy, LOW);
    analogWrite(pin_PWM_silnik_lewy, wartosc_PWM_1);
  }
  else
  {
    digitalWrite(pin_kierunek_silnik_lewy, HIGH);
    analogWrite(pin_PWM_silnik_lewy, wartosc_PWM_1);
  }
  //last_t = millis(); //
  last_uchyb_silnik_1 = uchyb_silnik_1; //

  //Prawy obrot
  if (wartosc_PWM_2 > PWM_max) wartosc_PWM_2 = PWM_max;
  if (uchyb_silnik_2 >= 0)
  {
    digitalWrite(pin_kierunek_silnik_prawy, LOW);
    analogWrite(pin_PWM_silnik_prawy, wartosc_PWM_2);
  }
  else
  {
    digitalWrite(pin_kierunek_silnik_prawy, HIGH);
    analogWrite(pin_PWM_silnik_prawy, wartosc_PWM_2);
  }
  last_uchyb_silnik_2 = uchyb_silnik_2; //

  last_t = millis(); //

}

long map(long x, long in_min, long in_max, long out_min, long out_max) {
  return (x - in_min) * (out_max - out_min) / (in_max - in_min) + out_min;
}

void odczyt_1()
{
  state_1_A = digitalRead(silnik_1_A);
  state_1_B = digitalRead(silnik_1_B);

  if (state_1_A == HIGH) {
    if (state_1_B == LOW) {
      silnik_1--;
    } else {
      silnik_1++;
    }
  }

  dp1 = silnik_1 - dp1_last;
  dp1_last = silnik_1;

  kat_1 = silnik_1 * 360 / 230;
}

void odczyt_2()
{
  state_2_A = digitalRead(silnik_2_A);
  state_2_B = digitalRead(silnik_2_B);

  if ((state_2_A == HIGH)) {
    if (state_2_B == LOW) {
      silnik_2++;
    } else {
      silnik_2--;
    }
  }

  dp2 = silnik_2 - dp2_last;
  dp2_last = silnik_2;

  kat_2 = silnik_2 * 360 / 230;
}

void odometria()
{
  Dl = Dl + (3.1415 * dp1) * d_kola / 230;
  Dp = Dp + (3.1415 * dp2) * d_kola / 230;

  D = (Dl + Dp) / 2;
  rot = (Dp - Dl) / rozstaw;
  if (rot >= 2 * 3.1415) {
    rot = rot - 2 * 3.1415;
  }
  rot_d = rot * 180 / 3.1415;
  x_n = x_n + (D - D_last) * cos(rot);
  y_n = y_n + (D - D_last) * sin(rot);
  D_last = D;
}

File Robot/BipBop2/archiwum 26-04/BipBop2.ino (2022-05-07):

float kd = 2;
double dt;
double last_t = 0;

float kp = 6;
float ki = 0;

//Parametry Ruchu
double t_Start;
double t_End;
double epsilon = 0.001; //przyspieszenie katowe [deg/ms/ms]

//Piny napedow
const byte silnik_1_A = 2;
const byte silnik_1_B = 5;
const byte silnik_2_A = 3;
const byte silnik_2_B = 6;

const int pin_kierunek_silnik_lewy = 7;
const int pin_PWM_silnik_lewy = 9;
const int pin_kierunek_silnik_prawy = 8 ;
const int pin_PWM_silnik_prawy = 10;

int wartosc_PWM_1_silnik_lewy = 0;
int wartosc_PWM_1_silnik_prawy = 0;
int PWM_max = 255;

//silnik_1 lewy
//silnik_2 prawy

long silnik_1;
long silnik_2;

int kat_1;
int kat_2;

//stan obecny
int state_1_A;
int state_1_B;
int state_2_A;
int state_2_B;

long potencjometr = 0;
const byte pin_potencjometr = 5;

//Lewy silnik PWM
double suma_bledow_1 = 0;
long kat_obrot_1 = 0;
float wartosc_PWM_1;
float uchyb_silnik_1 = 0;
float last_uchyb_silnik_1 = 0;
float szybk_bledow_1;

//Prawy silnik PWM
double suma_bledow_2 = 0;
long kat_obrot_2 = 0;
float wartosc_PWM_2;
float uchyb_silnik_2 = 0;
float last_uchyb_silnik_2 = 0;
float szybk_bledow_2;

double temp;

//Kola
int d_kola = 42;
int dp1, dp2;
int dp1_last, dp2_last;
double Dl, Dp;
double D, D_last;
float rot = 0, rot_d = 0, rozstaw = 100;
double x_n, y_n;

//Czas w petli
double petla_t1 = 0;
float Xt = 10;
double zad_t = 0; //Czas rozpoczecia wykonywania zadania
//Odbior
const int tabN = 10;
double tablica[tabN][5]; //tablica do odbioru danych o zadaniu. {Nr zadania, dlugosc (prosta/luk) [mm], czas wykonania [ms], promien luku [mm], kat rotacji w miejscu [deg]}
double bufor[5] = {0, 0, 0, 0, 0};
double T1, omega, l;
double *T0;

void setup() {
  // put your setup code here, to run once:
  pinMode(silnik_1_A, INPUT_PULLUP);
  pinMode(silnik_2_A, INPUT_PULLUP);
  attachInterrupt(digitalPinToInterrupt(silnik_1_A), odczyt_1, CHANGE);
  attachInterrupt(digitalPinToInterrupt(silnik_2_A), odczyt_2, CHANGE);

  pinMode(pin_kierunek_silnik_lewy, OUTPUT);
  pinMode(pin_PWM_silnik_lewy, OUTPUT);
  pinMode(pin_kierunek_silnik_prawy, OUTPUT);
  pinMode(pin_PWM_silnik_prawy, OUTPUT);

  Serial.begin(9600);

  T0 = &tablica[0][2];

  for (int i = 0; i < tabN; i++)
    for (int j = 0; j < 5; j++)
      tablica[i][j] = 0;


  //Reczne wypelninie tablicy
  tablica[0][0] = 2; //prosto
  tablica[0][1] = 50; //100mm
  tablica[0][2] = 3 * 1000; //w ... sekund

  tablica[1][0] = 1; //stoj
  tablica[1][1] = 0;
  tablica[1][2] = 3 * 1000; //przez ... sekund
}

void loop() {
  //tablica do odbioru danych o zadaniu. {Nr zadania, dlugosc (prosta/luk) [mm], czas wykonania [ms], promien luku [mm], kat rotacji w miejscu [deg]}


  //kat_obrot_1 = map(potencjometr, 0, 1021, -180, 180);
  //kat_obrot_2 = map(potencjometr, 0, 1021, -180, 180);



  //Petla co X ms, obsługa zadania
  if ((millis() - petla_t1) >= Xt) {
    petla_t1 = millis();
    if (tablica[0][0] > 0) { //Czy jest komenda do wykonania?

      if (tablica[0][0] == 1)//Stoj przez ...
        if (zad_t == 0) zad_t == millis(); //Jeżeli zadanie już nie trwa, zapisz czas rozpoczecia


      if (tablica[0][0] == 2) {//Jedz prosto
        if (zad_t == 0) {//Czy to rozpoczecie komendy?
          //Parametry ruchu
          //l = tablica[0][1] / 3.1416 / d_kola; //tu czy podzielic na 2?
          l = 2 * tablica[0][1] / d_kola;
          T1 = (epsilon * *T0  + sqrt((epsilon * *T0) * (epsilon * tablica[0][2])  + 2 * l * epsilon)) / (2 * epsilon); //4ac?
          Serial.println(T1);
          omega = epsilon * T1;

          zad_t == millis(); //Jeżeli zadanie już nie trwa, zapisz czas rozpoczecia
        }
        prosto();
      }


      if (tablica[0][0] == 3) {//Obrot
        if (zad_t == 0) {//Czy to rozpoczecie komendy?
          //Parametry ruchu
          //L=kat*rozstaw
          l = tablica[0][4] / 180 * 3.1416 * rozstaw / 3.1416 / d_kola; //tu czy podzielic na 2?
          T1 = (epsilon * *T0  + sqrt((epsilon * *T0) * (epsilon * tablica[0][2])  + 2 * l * epsilon)) / (2 * epsilon); //4ac?
          omega = epsilon * T1;

          zad_t == millis(); //Jeżeli zadanie już nie trwa, zapisz czas rozpoczecia
        }
        obrot();
      }

      if (millis() - zad_t > tablica[0][2])koniec_CMD(); //Uplynal czas na wykonanie komendy
    }
  }

  PWM(); //PWM na napedy

  odometria();
  delay(1);
}

void obrot() {
//jak prosto, tylko przeciwne kierunki ruchu
}

void prosto() {

  double pr_t = millis();

  double T1_now = pr_t + T1;
  double T0_now = pr_t + *T0;
  double katL0 = kat_1;
  double katP0 = kat_2;
  long kat_obrot = 0;
  if (pr_t <= T1_now) //Czy przyspiesza?
  {
    Serial.println(1);
    kat_obrot = epsilon * millis() * millis() / 2;
  }
  else if (pr_t <= (T0_now - T1_now))  //Czy stala predkosc?
  {
    Serial.println(2);
    kat_obrot = epsilon * T1 * T1 / 2 + omega * (millis() - T1);
  }

  else if (pr_t <= T0_now)//Czy zwalnia?
  {
    Serial.println(3);
    kat_obrot = epsilon * T1 * T1 / 2 + omega * (*T0 - T1) - epsilon * (millis() - *T0 + T1) * (millis() - *T0 + T1) / 2;
  }
  kat_obrot_1 = kat_obrot;
  kat_obrot_2 = kat_obrot;
}

void koniec_CMD() {
  for (int i = 0; i < tabN - 1; i++)
    for (int j = 0; j < 5; j++)
      tablica[i][j] = tablica[i + 1][j];
}

void PWM() {
  dt = millis() - last_t; //
  //Lewy PWM
  uchyb_silnik_1 = kat_obrot_1 - kat_1;
  suma_bledow_1 = suma_bledow_1 + uchyb_silnik_1 * dt; //
  szybk_bledow_1 = (uchyb_silnik_1 - last_uchyb_silnik_1) / dt; //
  wartosc_PWM_1 = abs(uchyb_silnik_1 * kp + ki * suma_bledow_1 + kd * szybk_bledow_1); //

  //Prawy PWM
  uchyb_silnik_2 = kat_obrot_2 - kat_2;
  suma_bledow_2 = suma_bledow_2 + uchyb_silnik_2 * dt; //
  szybk_bledow_2 = (uchyb_silnik_2 - last_uchyb_silnik_2) / dt; //
  wartosc_PWM_2 = abs(uchyb_silnik_2 * kp + ki * suma_bledow_2 + kd * szybk_bledow_2); //

  //Lewy obrot
  if (wartosc_PWM_1 > PWM_max) wartosc_PWM_1 = PWM_max;
  if (uchyb_silnik_1 >= 0)
  {
    digitalWrite(pin_kierunek_silnik_lewy, LOW);
    analogWrite(pin_PWM_silnik_lewy, wartosc_PWM_1);
  }
  else
  {
    digitalWrite(pin_kierunek_silnik_lewy, HIGH);
    analogWrite(pin_PWM_silnik_lewy, wartosc_PWM_1);
  }
  //last_t = millis(); //
  last_uchyb_silnik_1 = uchyb_silnik_1; //

  //Prawy obrot
  if (wartosc_PWM_2 > PWM_max) wartosc_PWM_2 = PWM_max;
  if (uchyb_silnik_2 >= 0)
  {
    digitalWrite(pin_kierunek_silnik_prawy, LOW);
    analogWrite(pin_PWM_silnik_prawy, wartosc_PWM_2);
  }
  else
  {
    digitalWrite(pin_kierunek_silnik_prawy, HIGH);
    analogWrite(pin_PWM_silnik_prawy, wartosc_PWM_2);
  }
  last_uchyb_silnik_2 = uchyb_silnik_2; //

  last_t = millis(); //

}

void odbior() {
  int i = 0;
  //dodac jezeli tablica pelna wywal blad
  //while (tablica[i][0] != 0 && i < tabN) {
  //  i++; //przy implementacji komunikacji usunac przy tabN
  //}

  tablica[i][0] = 2; //prosto
  tablica[i][1] = 50; //100mm
  tablica[i][2] = 3 * 1000; //w ... sekund

  tablica[i + 1][0] = 1; //stoj
  tablica[i + 1][1] = 0;
  tablica[i + 1][2] = 3 * 1000; //przez ... sekund

}
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

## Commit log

2022-03-21 Dodaj pliki projektów.
    [Frame 1647020232368.0001.iam, Frame 1647020232368.iam, ISO 10799-2 40x40x2 1647020233901.ipt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]
2022-04-05 aruco detection camera calibration saving json
2022-04-05 calibration images
2022-04-06 bez printow w working area
2022-05-08 xbee frame class
2022-05-08 basic description of raspberry
2022-05-09 better json receiving socket.timeout handler RPI
